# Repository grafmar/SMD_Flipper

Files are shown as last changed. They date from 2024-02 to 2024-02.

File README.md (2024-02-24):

# SMD_Flipper
Device to flip SMD components, especially useful for manual pick and place machine

## Hardware
- 2 x SG90 servo motor
- Arduino Nano or ATTiny85
- button to start the flipping process

The Servos can be controlled by an Arduino Nano. I also tried to
control it with an ATTiny. This works but for convinience I
switched back to an Arduino Nano.

The button is used to start the flipping process and after the
flipping the servos are deactivated by switching off the control
line of the servos.

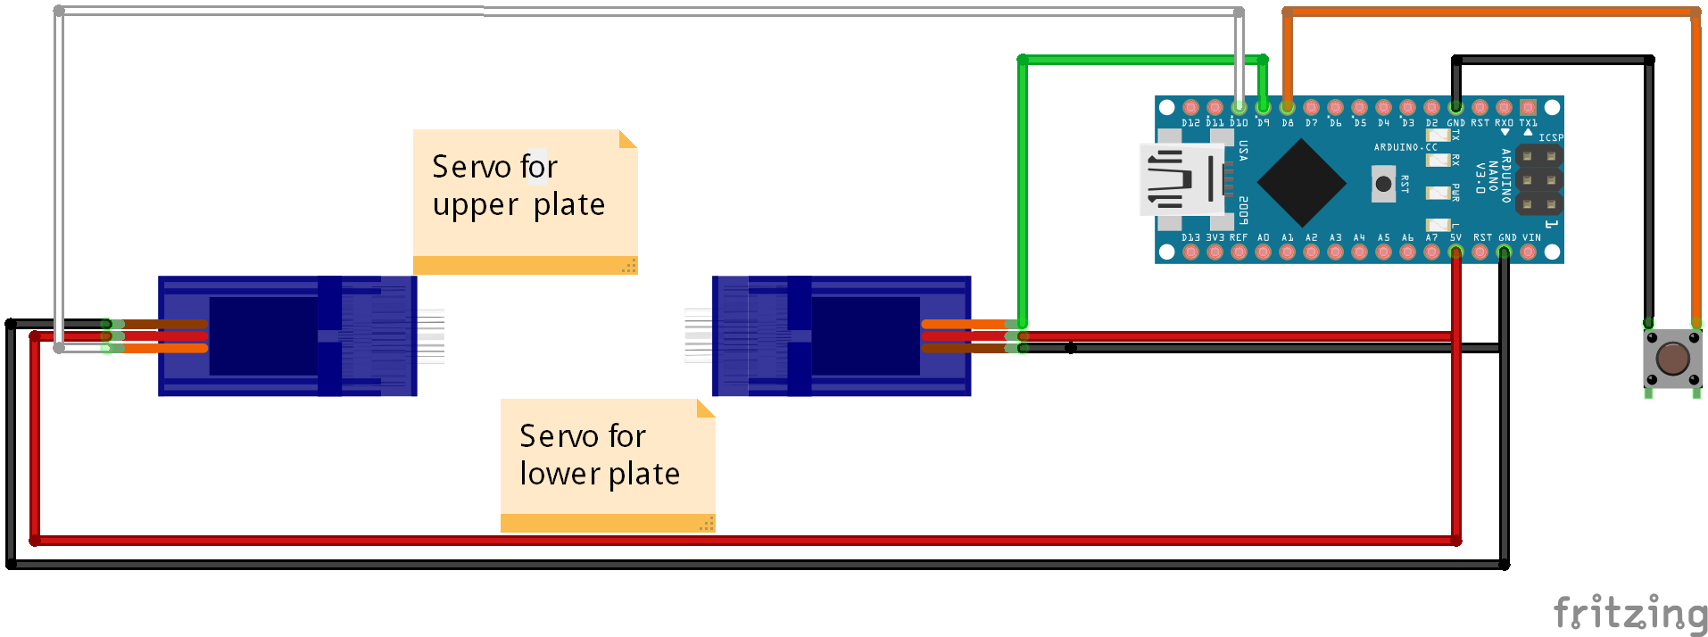
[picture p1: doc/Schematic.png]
Schematic


## Software
### Arduino Nano version
- [Arduino IDE](https://www.arduino.cc/en/main/software) (V 2.3.2)
- [PrecisionServo](https://github.com/ElizabethTeaches/PrecisionServo) by Elizabeth Teaches

### ATTiny85 version
- [Arduino IDE](https://www.arduino.cc/en/main/software) (V 2.3.2)
- Board support "attiny by Deavind A. Mellis" (V 1.0.2)
  - add Additional boards manager URL in Preferences: https://raw.githubusercontent.com/damellis/attiny/ide-1.6.x-boards-manager/package_damellis_attiny_index.json
  - set board to attiny->ATtiny25/45/85
  - set Processor to ATtiny85
  - set clock to Internal 16MHz
  - set to your Programmer
  - Burn Bootloader
  - Upload Using Programmer

## Author
[Marco Graf](https://github.com/grafmar)

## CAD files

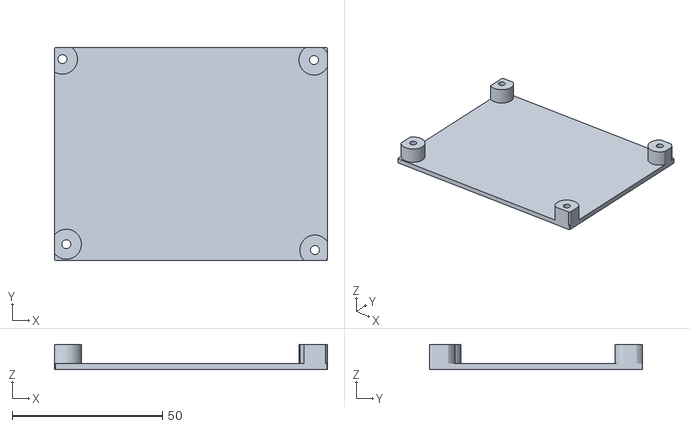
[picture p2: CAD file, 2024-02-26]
mechanics/SMD_Flipper_Housing_Lid.stl
91.0 x 71.0 x 8.40

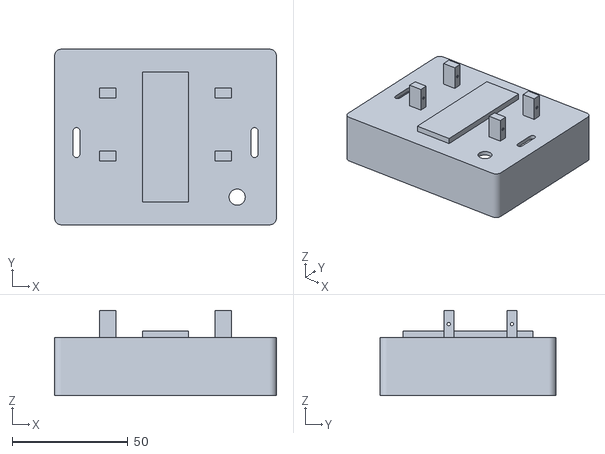
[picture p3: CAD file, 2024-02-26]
mechanics/SMD_Flipper_Housing.stl
96.0 x 76.0 x 36.8

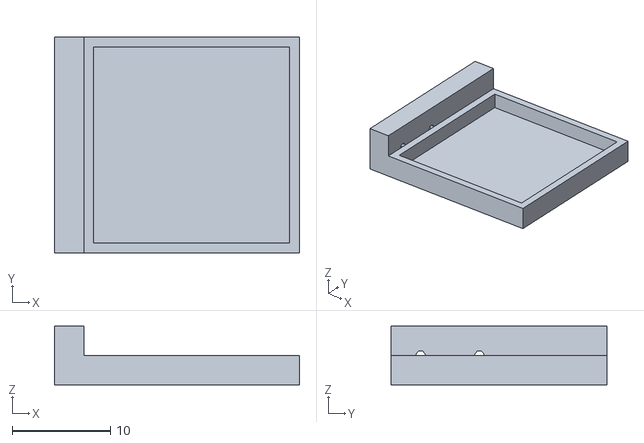
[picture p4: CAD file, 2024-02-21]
mechanics/SMD_Flipper_Plate.stl
25.0 x 22.0 x 6.00

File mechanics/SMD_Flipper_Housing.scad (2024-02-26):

servoOffset=57;
servoScrewOffset=27.3;
servoScrewDia=1.5;
servoWidth=22.5;
servoThickness=11.8;
servoAxisOffset=22.5/2-5.9;
clearance=0.5;
plateOuterDistance=28;

HousingInnerHeight=25;
HousingInnerWidth=92;
HousingInnerLength=72;
HousingRoundness=3;
thickness=2;


plateXX=20;
plateYY=20;
plateThickness=1;
foamThickness=2;
$fs=0.5;
$fa=2;

// Screw positions
screwXX=91/2-1.5;
screwYY=70/2-1.5;
pos=[
[-(screwXX-1.2) ,(screwYY-1.9)],
[(screwXX-3)    ,(screwYY-2.2)],
[-(screwXX-2.5) ,-(screwYY-3.45)],
[(screwXX-2.7)  ,-(screwYY-1.5)]];



// Housing
housing();
//lid();


module housing() {
    lowerHousing();
    
    // Plate support
    translate([-plateXX/2,-plateOuterDistance,0])cube([plateXX,2*plateOuterDistance,servoThickness/2-plateThickness-foamThickness]);

    // Servo mount
    servoMount();
    mirror([1,0,0]) servoMount();
    module servoMount(){
        for(i=[-1,1])translate([servoOffset/2-7/2,i*servoScrewOffset/2+servoAxisOffset,servoThickness/2])difference(){
            cube([7,servoScrewOffset-servoWidth-clearance,servoThickness],center=true);
            rotate([0,90,0])cylinder(d=servoScrewDia,h=8,center=true);
        }
    }
}

module lowerHousing() {
    xOffset=(HousingInnerWidth-(2*HousingRoundness-2*thickness))/2;
    yOffset=(HousingInnerLength-(2*HousingRoundness-2*thickness))/2;
    PcbTop=-15;
    
    difference() {
        hull() for(ix=[-1,1])for(iy=[-1,1])translate([ix*xOffset,iy*yOffset,-HousingInnerHeight])cylinder(r=HousingRoundness,h=HousingInnerHeight);
        
        // inner
        hull() for(ix=[-1,1])for(iy=[-1,1])translate([ix*xOffset,iy*yOffset,-HousingInnerHeight-thickness])cylinder(r=HousingRoundness-thickness,h=HousingInnerHeight);
            
        // Servo cable holes
        for(ix=[-1,1])hull()for(yy=[0,10])translate([ix*(servoOffset/2+10),servoAxisOffset-servoWidth/2-3/2+yy,0])cylinder(d=3,h=thickness*3,center=true);
            
        // USB Hole
        hull()for(ix=[-1,1])for(iy=[-1,1])translate([ix*10/2+2.54/2,yOffset,iy*7/2+PcbTop+7])rotate([90,0,0])
            cylinder(d=4,h=3*thickness,center=true);
        
        // Button
        translate([HousingInnerWidth/2-15,-(HousingInnerLength/2-10),0])cylinder(d=7,h=3*thickness,center=true);
    }
    
    // screws
    corners=[
    [-xOffset ,yOffset],
    [xOffset ,yOffset],
    [-xOffset ,-yOffset],
    [xOffset ,-yOffset]];
    for(i=[0:3])translate([pos[i][0],pos[i][1],PcbTop])difference(){
        hull(){
            cylinder(d=6,h=-PcbTop-thickness);
            translate([corners[i][0]-pos[i][0],corners[i][1]-pos[i][1],0])cylinder(r=HousingRoundness,h=-PcbTop-thickness);
        }
        translate([0,0,-3])cylinder(d=3,h=-PcbTop-thickness);
    }
}

module lid() {
    xOffset=(HousingInnerWidth-(2*HousingRoundness-2*thickness))/2;
    yOffset=(HousingInnerLength-(2*HousingRoundness-2*thickness))/2;
    PcbTop=-15;
    
    difference() {
        union(){
            hull() for(ix=[-1,1])for(iy=[-1,1])translate([ix*xOffset,iy*yOffset,-HousingInnerHeight])cylinder(r=HousingRoundness-thickness-clearance,h=thickness);
                
            // screw shaft
            for(i=[0:3])intersection(){
                translate([pos[i][0],pos[i][1],-HousingInnerHeight])cylinder(d=6+2*thickness,h=HousingInnerHeight+PcbTop-1.6);
                
                hull() for(ix=[-1,1])for(iy=[-1,1])translate([ix*xOffset,iy*yOffset,-HousingInnerHeight])cylinder(r=HousingRoundness-thickness-clearance,h=HousingInnerHeight);
            }            
        }
        
        // screws holes
        for(i=[0:3])translate([pos[i][0],pos[i][1],-HousingInnerHeight-0.01]){
            cylinder(d=6,h=HousingInnerHeight+PcbTop-1.6-thickness);
            cylinder(d=3,h=HousingInnerHeight);
        }
    }
}


//plate();
module plate() {
thickness=plateThickness;
translate([0,0,servoThickness/2])union(){
    difference() {
        translate([-plateXX/2-thickness,5,-(thickness+foamThickness)])cube([plateXX+2*thickness,plateYY+2*thickness,thickness+foamThickness]);
        translate([-plateXX/2,5+thickness,-foamThickness])cube([plateXX,plateYY,thickness+foamThickness]);
    }
    
    difference(){
        translate([-3-plateXX/2-thickness,5,-(thickness+foamThickness)])cube([3,plateYY+2*thickness,2*(thickness+foamThickness)]);
        //14, 8
        translate([-plateXX/2-thickness,8,0])rotate([0,90,0])cylinder(d=1,h=3*3,center=true);
        translate([-plateXX/2-thickness,14,0])rotate([0,90,0])cylinder(d=1,h=3*3,center=true);
    }
}
}

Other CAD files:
mechanics/SMD_Flipper_Plate.scad

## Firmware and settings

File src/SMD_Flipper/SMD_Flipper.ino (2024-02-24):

/*
 Control servos for SMD component flipper
 */

#include <Servo.h>

const uint16_t servo1_pin = 9;
const uint16_t servo2_pin = 10;
const uint16_t button_pin = 8;

Servo myservoA;  // create servo object to control a servo
Servo myservoB;  // create servo object to control a servo

uint16_t posA = 0;    // variable to store the servo position
uint16_t posB = 0;    // variable to store the servo position

void setup() {
  myservoA.write(posA);              // tell servo to go to position in variable 'pos'
  myservoB.write(posB);              // tell servo to go to position in variable 'pos'
  myservoA.attach(servo1_pin);  // attaches the servo on pin 9 to the servo object
  myservoB.attach(servo2_pin);  // attaches the servo on pin 9 to the servo object

  pinMode(servo1_pin, INPUT_PULLUP);
  pinMode(servo2_pin, INPUT_PULLUP);
  pinMode(button_pin, INPUT_PULLUP);
}

void loop() {
  if (digitalRead(button_pin) == LOW) {
    // power servos
    pinMode(servo1_pin, OUTPUT);
    pinMode(servo2_pin, OUTPUT);
    // do movement
    goPos(0,180,400);
    goPos(180,0,400);
    goPos(0,0,400);
    // unpower servos
    pinMode(servo1_pin, INPUT_PULLUP);
    pinMode(servo2_pin, INPUT_PULLUP);
  }
}

void goPos(uint16_t a,uint16_t b,uint16_t delayForMovement) {
  myservoA.write(a);
  myservoB.write(b);
  delay(delayForMovement);
}

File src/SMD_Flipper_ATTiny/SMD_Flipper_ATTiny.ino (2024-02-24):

/*
 Direct servo control by turning hardcoded PWM signal using delayMicroseconds().
 This is to control the SMD component flipper.
*/

const uint16_t servo1_pin = 0;
const uint16_t servo2_pin = 1;
const uint16_t button_pin = 2;

// Theoretical values
/*
#define MICROSECONDS_FOR_180 2000
#define MICROSECONDS_FOR_0 1000
#define MICROSECONDS_FOR_CYCLE 20000
*/
// Practical values
#define MICROSECONDS_FOR_180 2400
#define MICROSECONDS_FOR_0 500
#define MICROSECONDS_FOR_CYCLE 20600

void setup() {
  pinMode(servo1_pin, OUTPUT);
  pinMode(servo2_pin, OUTPUT);
  pinMode(button_pin, INPUT_PULLUP);
  digitalWrite(servo1_pin, LOW);
  digitalWrite(servo2_pin, LOW);
}

void loop() {
  if (digitalRead(button_pin) == LOW) {
    servoApply(MICROSECONDS_FOR_0,MICROSECONDS_FOR_180,600);
    servoApply(MICROSECONDS_FOR_180,MICROSECONDS_FOR_0,600);
    servoApply(MICROSECONDS_FOR_0,MICROSECONDS_FOR_0,800);
  }
}

void servoApply(uint32_t servoOnTime1, uint32_t servoOnTime2, uint32_t durationMS) {
  const uint32_t cycles = durationMS * 1000UL / MICROSECONDS_FOR_CYCLE;
  const uint32_t filltime = MICROSECONDS_FOR_CYCLE - servoOnTime1 - servoOnTime2;
  for(uint32_t i=0; i<cycles; i++) {
    digitalWrite(servo1_pin, HIGH);
    delayMicroseconds(servoOnTime1);
    digitalWrite(servo1_pin, LOW);
    digitalWrite(servo2_pin, HIGH);
    delayMicroseconds(servoOnTime2);
    digitalWrite(servo2_pin, LOW);
    delay(filltime/1000);
    delayMicroseconds(filltime%1000);
  }
}

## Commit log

2024-02-21 First SW tests with Arduino Nano
2024-02-21 Plates to connect to servo motors
    [SMD_Flipper_Plate.scad, SMD_Flipper_Plate.stl]
2024-02-24 Differnetiate Arduino Nano and ATtiny version
2024-02-24 Added Button input and cleanup
2024-02-24 Added schematic
    [Schematic.fzz]
2024-02-24 Added Housing
    [SMD_Flipper_Housing.scad, SMD_Flipper_Housing.stl]
2024-02-26 updated housing and added lid
    [SMD_Flipper_Housing.scad, SMD_Flipper_Housing.stl, SMD_Flipper_Housing_Lid.stl]
